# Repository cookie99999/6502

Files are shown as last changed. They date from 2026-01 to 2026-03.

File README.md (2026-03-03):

These are the relevant files for my ongoing WDC 65C816 based homebrew computer. It started off pretty similar to Ben Eater's 65C02 computer, but I've made significant changes since then and will continue to do so.

## Current Specs:
- WDC 65C816 clocked at 4MHz (reasonably stable at 6MHz, fails to boot at 8 likely due to slow memory/logic)
- 512K SRAM
- 8K NOR flash accessible to the user
- 2 6522 VIAs providing 2 8-bit GPIO ports and a couple timers and shift registers each
- 6551 ACIA UART for serial I/O. Rockwell part works only up to about 4MHz, but avoids the TX empty flag bug of the WDC part
- PS/2 interface provided by ATTiny26L on one of the VIA ports
- CompactFlash storage (via PATA adapter)
- VGA video output from a Pi Pico 2 providing text display and (very slow) bitmapped graphics
- expensive and oversized 4-layer PCB

## To do list:
- Bitbang an SPI RTC on a remaining VIA port
- possibly look into sound and/or joysticks on the other 2
- new PCB layout using more SMD/PLCC parts to reduce size and cost, with more SRAM and a proper DE-9 serial port

I've used and modified ideas from many sources, notably Ben Eater, Garth Wilson, Daryl Rictor, Grant Searle, and many users and articles on the 6502.org forum.

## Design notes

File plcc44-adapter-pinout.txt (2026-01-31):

dip  plcc
1    2
2    3 VCC
3    4
4    5
5    6
6    7 TDI
7    8
8    9
9    10 GND
10   11
11   13 TMS
12   14
13   15 VCC
14   NC
15   17
16   18
17   19
18   20
19   21
20   22 GND
21   24
22   25
23   26
24   27
25   28
26   29
27   30 GND
28   31
29   32 TCK
30   33
31   35 VCC
32   36
33   37
34   38 TDO
35   39
36   40
37   41
38   42 GND
39   43
40   44 OE1

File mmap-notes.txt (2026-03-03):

000000-00deff: ram
00df00-00df4f: io space, 16 bytes each for 5 devices
00df50-00dfff: unmapped
00e000-00ffff: rom
010000-ffffff: ram (currently 512k installed)

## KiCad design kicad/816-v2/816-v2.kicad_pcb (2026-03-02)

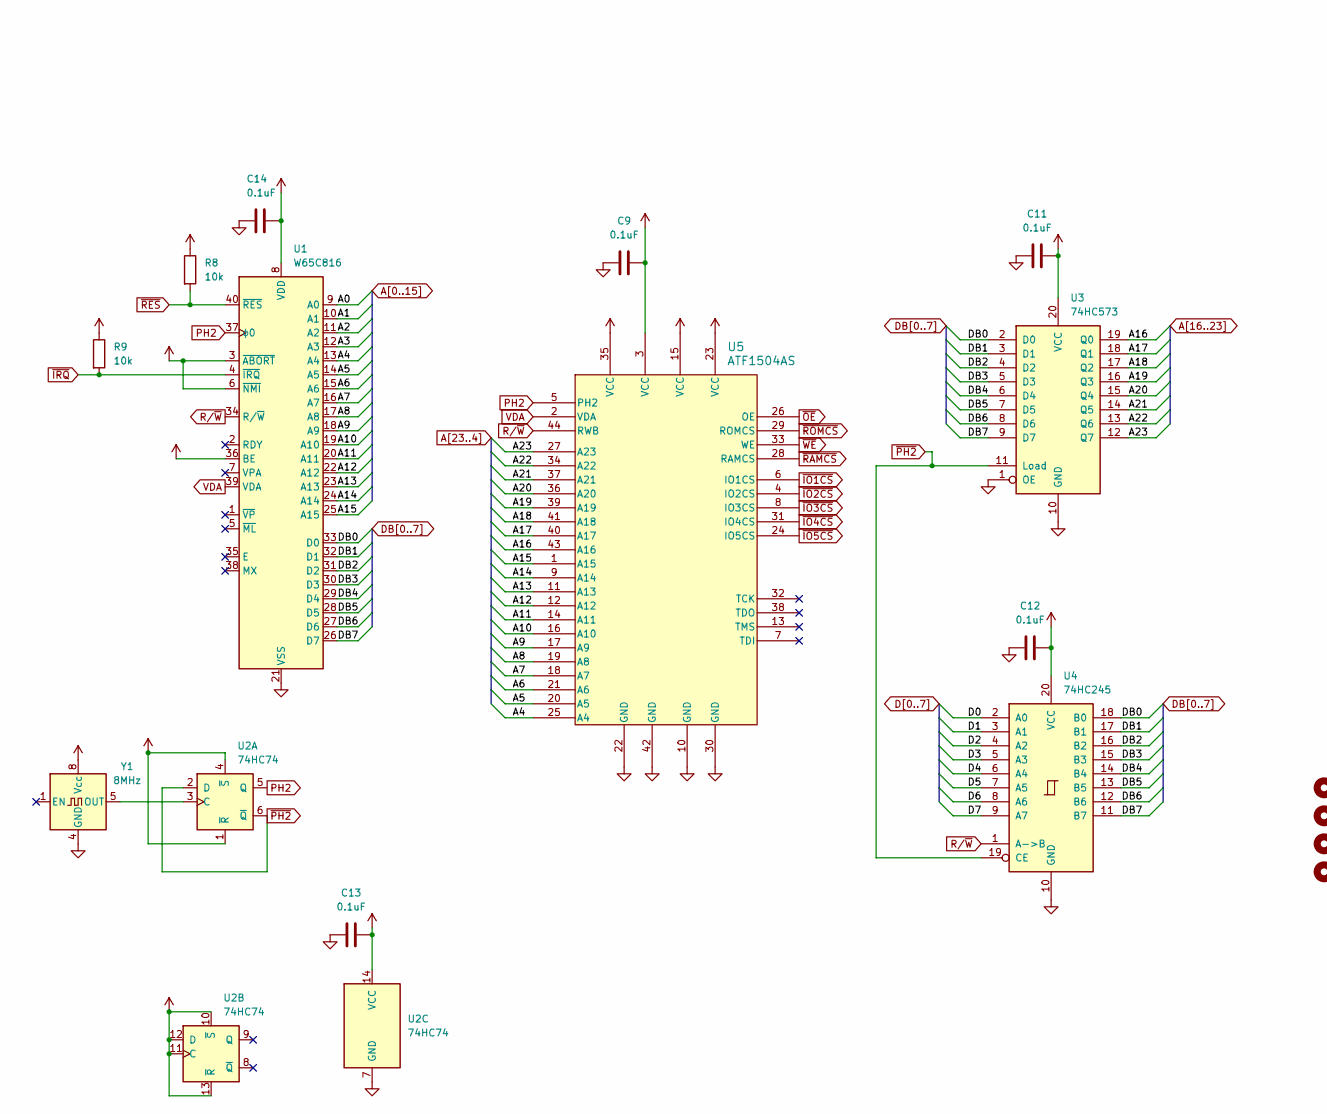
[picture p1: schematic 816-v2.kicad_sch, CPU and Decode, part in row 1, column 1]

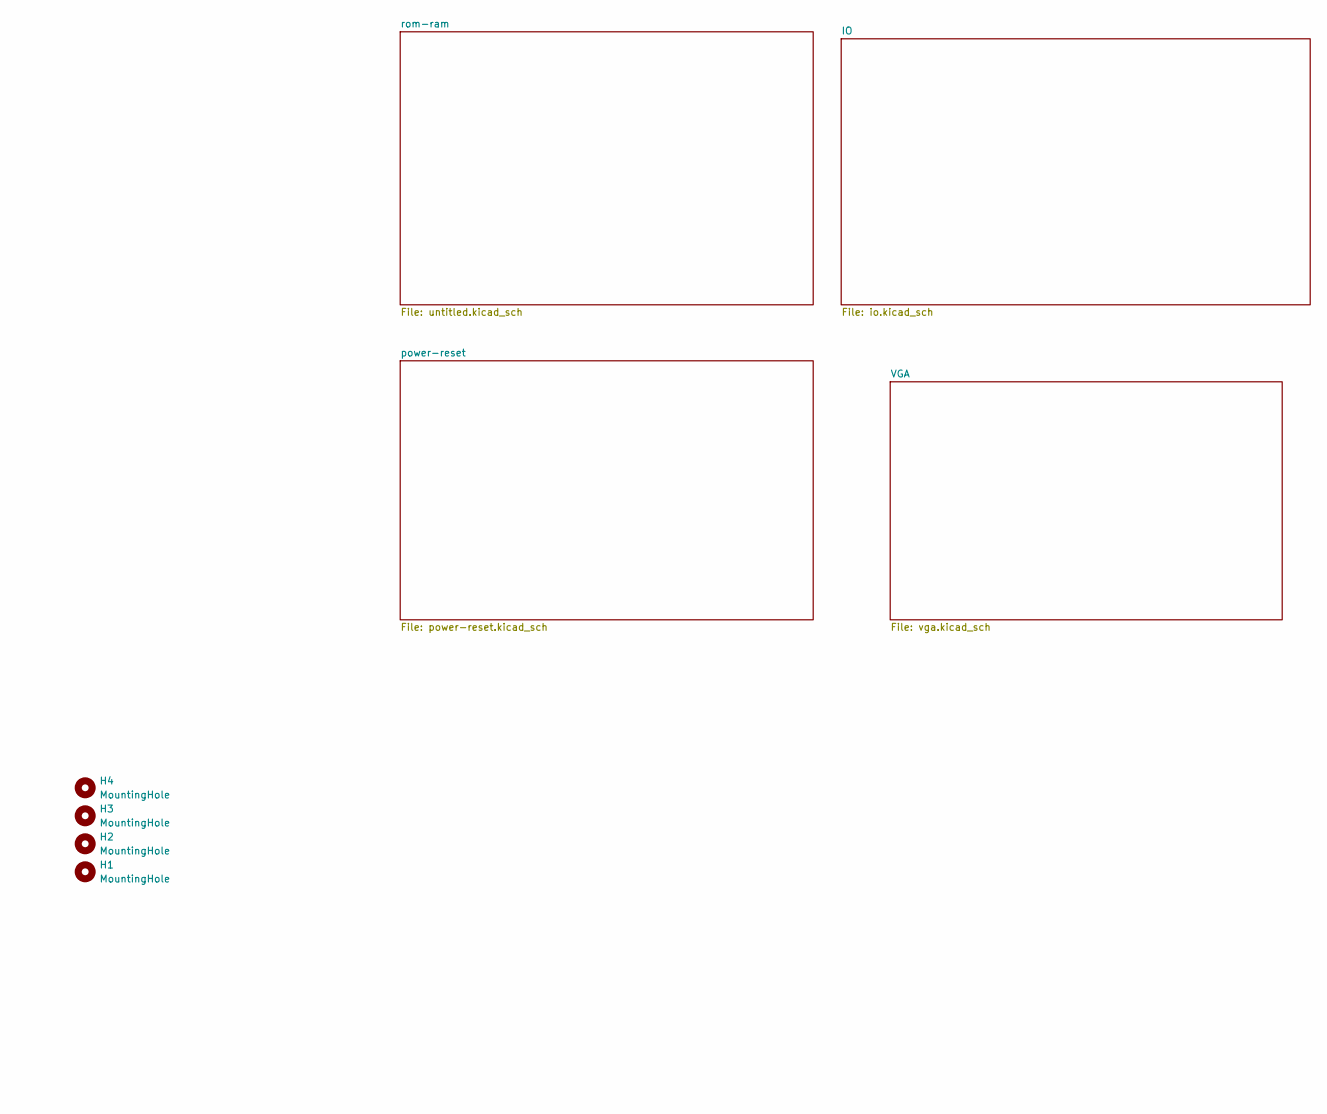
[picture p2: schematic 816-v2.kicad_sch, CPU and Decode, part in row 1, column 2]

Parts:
C9, C11, C12, C13, C14: 0.1uF; C_Disc_D4.3mm_W1.9mm_P5.00mm
H1, H2, H3, H4: MountingHole; MountingHole_3.2mm_M3
R8, R9: 10k; R_Axial_DIN0207_L6.3mm_D2.5mm_P7.62mm_Horizontal
U1: W65C816; DIP-40_W15.24mm_Socket
U2: 74HC74; DIP-14_W7.62mm_Socket
U3: 74HC573; DIP-20_W7.62mm_Socket
U4: 74HC245; DIP-20_W7.62mm_Socket
U5: ATF1504AS; PLCC-44_THT-Socket
Y1: 8MHz; DIP-8_W7.62mm_Socket

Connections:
A0: U1.9 (A0); also elsewhere on the board
A1: U1.10 (A1); also elsewhere on the board
A2: U1.11 (A2); also elsewhere on the board
A3: U1.12 (A3); also elsewhere on the board
A4: U1.13 (A4), U5.25 (A4); also elsewhere on the board
A5: U1.14 (A5), U5.20 (A5); also elsewhere on the board
A6: U1.15 (A6), U5.21 (A6); also elsewhere on the board
A7: U1.16 (A7), U5.18 (A7); also elsewhere on the board
A8: U1.17 (A8), U5.19 (A8); also elsewhere on the board
A9: U1.18 (A9), U5.17 (A9); also elsewhere on the board
A10: U1.19 (A10), U5.16 (A10); also elsewhere on the board
A11: U1.20 (A11), U5.14 (A11); also elsewhere on the board
A12: U1.22 (A12), U5.12 (A12); also elsewhere on the board
A13: U1.23 (A13), U5.11 (A13); also elsewhere on the board
A14: U1.24 (A14), U5.9 (A14); also elsewhere on the board
A15: U1.25 (A15), U5.1 (A15); also elsewhere on the board
A16: U3.19 (Q0), U5.43 (A16); also elsewhere on the board
A17: U3.18 (Q1), U5.40 (A17); also elsewhere on the board
A18: U3.17 (Q2), U5.41 (A18); also elsewhere on the board
A19: U3.16 (Q3), U5.39 (A19)
A20: U3.15 (Q4), U5.36 (A20)
A21: U3.14 (Q5), U5.37 (A21)
A22: U3.13 (Q6), U5.34 (A22)
A23: U3.12 (Q7), U5.27 (A23)
D0: U4.2 (A0); also elsewhere on the board
D1: U4.3 (A1); also elsewhere on the board
D2: U4.4 (A2); also elsewhere on the board
D3: U4.5 (A3); also elsewhere on the board
D4: U4.6 (A4); also elsewhere on the board
D5: U4.7 (A5); also elsewhere on the board
D6: U4.8 (A6); also elsewhere on the board
D7: U4.9 (A7); also elsewhere on the board
DB0: U1.33 (D0), U3.2 (D0), U4.18 (B0)
DB1: U1.32 (D1), U3.3 (D1), U4.17 (B1)
DB2: U1.31 (D2), U3.4 (D2), U4.16 (B2)
DB3: U1.30 (D3), U3.5 (D3), U4.15 (B3)
DB4: U1.29 (D4), U3.6 (D4), U4.14 (B4)
DB5: U1.28 (D5), U3.7 (D5), U4.13 (B5)
DB6: U1.27 (D6), U3.8 (D6), U4.12 (B6)
DB7: U1.26 (D7), U3.9 (D7), U4.11 (B7)
GND: C9.1, C11.2, C12.2, C13.2, C14.1, U1.21 (VSS), U2.7 (GND), U3.1 (OE), U3.10 (GND), U4.10 (GND), U5.10 (GND), U5.22 (GND), U5.30 (GND), U5.42 (GND), Y1.4 (GND); also elsewhere on the board
unnamed: U2.3 (C), Y1.5 (OUT)
PH2: U1.37 (ϕ0), U2.5 (Q), U5.5 (PH2); also elsewhere on the board
R/~W: U1.34 (R/~W), U4.1 (A->B), U5.44 (RWB); also elsewhere on the board
VCC: C9.2, C11.1, C12.1, C13.1, C14.2, R8.1, R9.1, U1.3 (~ABORT), U1.6 (~NMI), U1.8 (VDD), U1.36 (BE), U2.1 (~R), U2.4 (~S), U2.10 (~S), U2.11 (C), U2.12 (D), U2.13 (~R), U2.14 (VCC), U3.20 (VCC), U4.20 (VCC), U5.3 (VCC), U5.15 (VCC), U5.23 (VCC), U5.35 (VCC), Y1.8 (Vcc); also elsewhere on the board
VDA: U1.39 (VDA), U5.2 (VDA)
~IO1CS: U5.6 (IO1CS); also elsewhere on the board
~IO2CS: U5.4 (IO2CS); also elsewhere on the board
~IO3CS: U5.8 (IO3CS); also elsewhere on the board
~IO4CS: U5.31 (IO4CS); also elsewhere on the board
~IO5CS: U5.24 (IO5CS); also elsewhere on the board
~IRQ: R9.2, U1.4 (~IRQ); also elsewhere on the board
~OE: U5.26 (OE); also elsewhere on the board
~PH2: U2.2 (D), U2.6 (~Q), U3.11 (Load), U4.19 (CE)
~RAMCS: U5.28 (RAMCS); also elsewhere on the board
~RES: R8.2, U1.40 (~RES); also elsewhere on the board
~ROMCS: U5.29 (ROMCS); also elsewhere on the board
~WE: U5.33 (WE); also elsewhere on the board

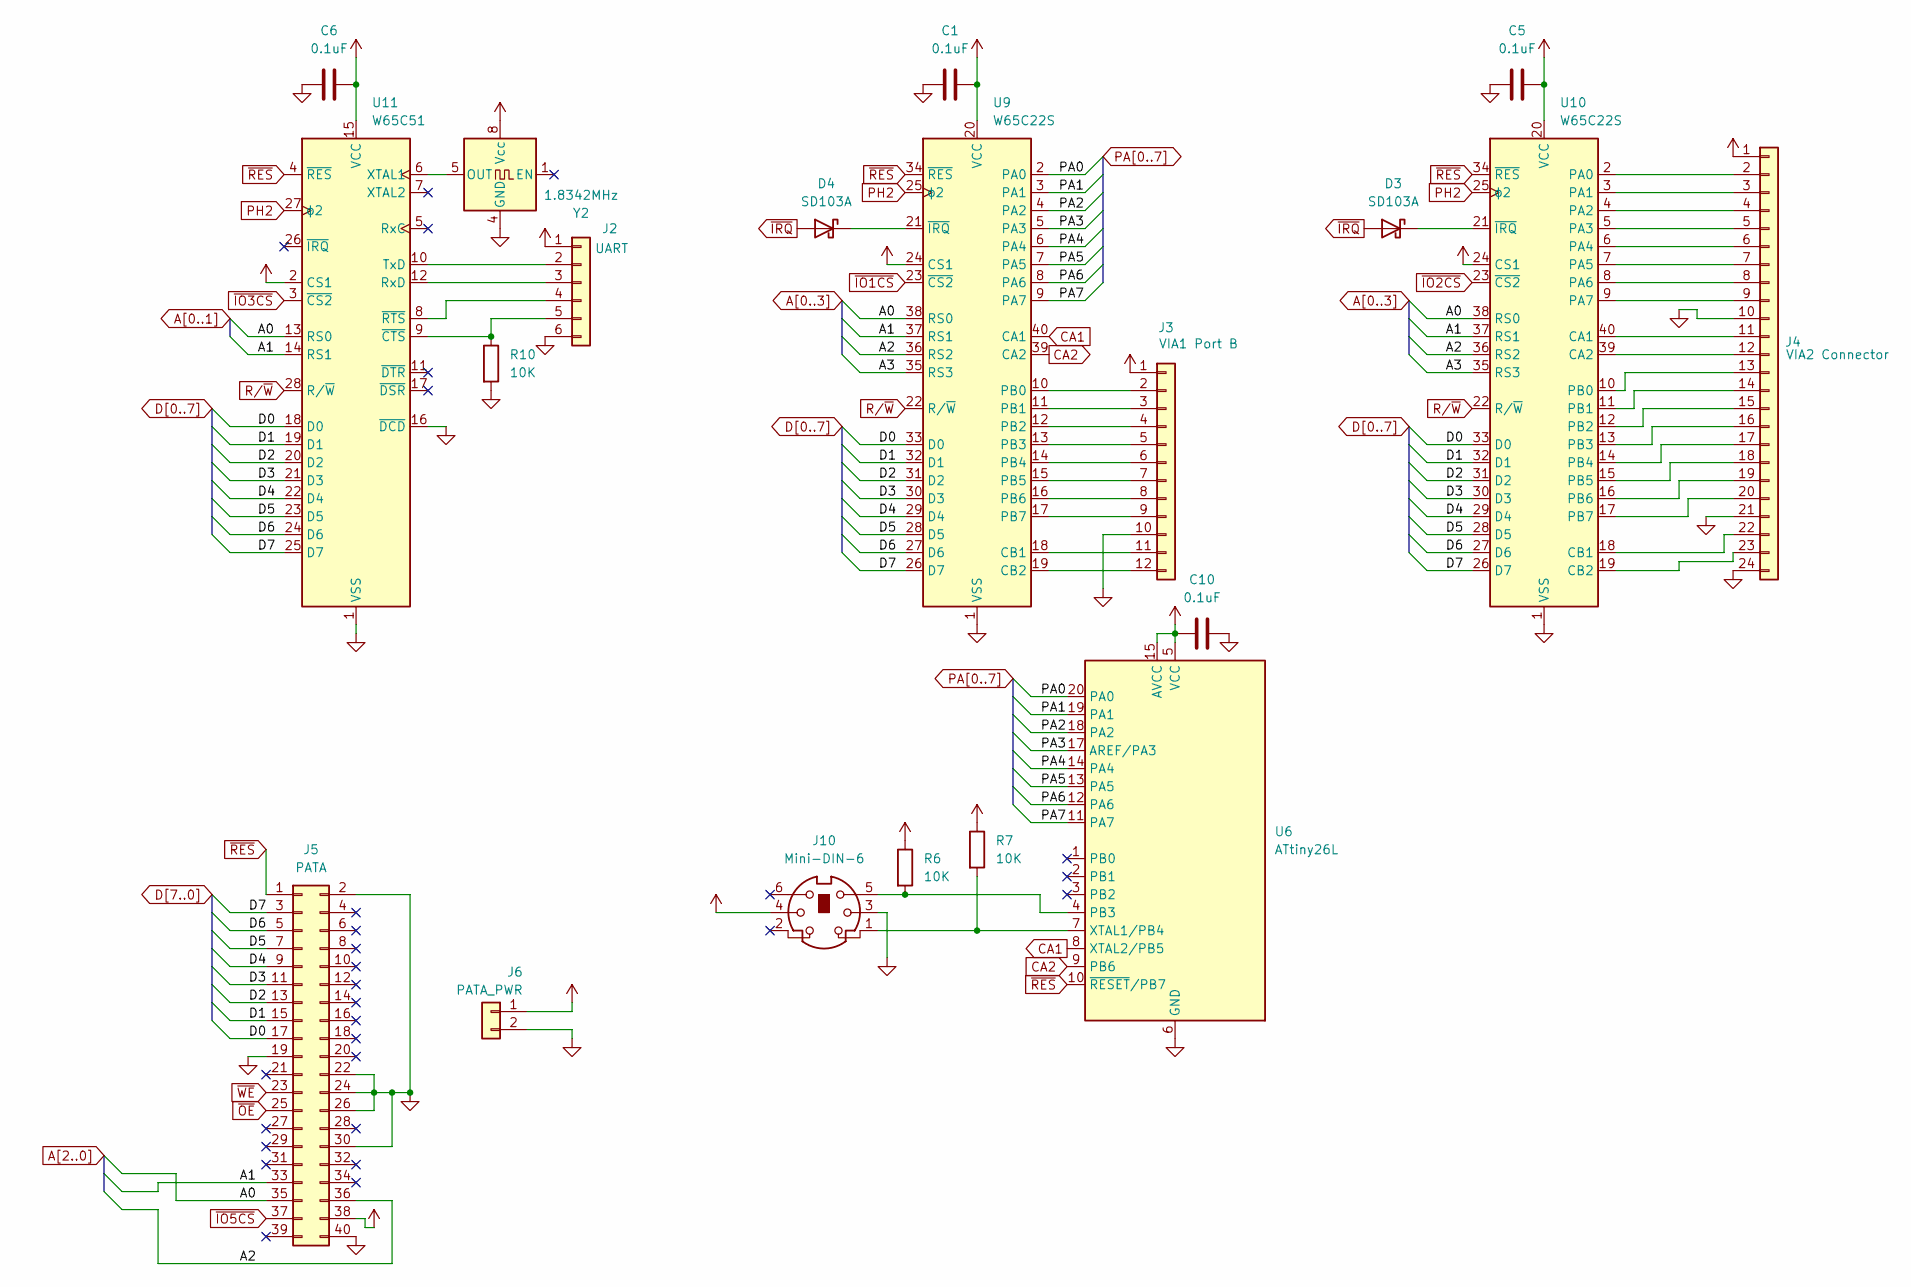
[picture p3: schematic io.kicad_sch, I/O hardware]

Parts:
C1, C5, C6, C10: 0.1uF; C_Disc_D4.3mm_W1.9mm_P5.00mm
D3, D4: SD103A; D_DO-35_SOD27_P7.62mm_Horizontal
J2: UART; PinHeader_1x06_P2.54mm_Vertical
J3: VIA1 Port B; PinHeader_2x06_P2.54mm_Vertical
J4: VIA2 Connector; PinHeader_2x12_P2.54mm_Vertical
J5: PATA; IDC-Header_2x20_P2.54mm_Vertical
J6: PATA_PWR; PinHeader_1x02_P2.54mm_Vertical
J10: Mini-DIN-6; TE_5749180-1
R6, R7, R10: 10K; R_Axial_DIN0207_L6.3mm_D2.5mm_P7.62mm_Horizontal
U6: ATtiny26L; DIP-20_W7.62mm_Socket
U9, U10: W65C22S; DIP-40_W15.24mm_Socket
U11: W65C51; DIP-28_W15.24mm_Socket
Y2: 1.8342MHz; Oscillator_DIP-8

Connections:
A0: J5.35, U9.38 (RS0), U10.38 (RS0), U11.13 (RS0); also elsewhere on the board
A1: J5.33, U9.37 (RS1), U10.37 (RS1), U11.14 (RS1); also elsewhere on the board
A2: J5.36, U9.36 (RS2), U10.36 (RS2); also elsewhere on the board
A3: U9.35 (RS3), U10.35 (RS3); also elsewhere on the board
CA1: U6.8 (XTAL2/PB5), U9.40 (CA1)
CA2: U6.9 (PB6), U9.39 (CA2)
D0: J5.17, U9.33 (D0), U10.33 (D0), U11.18 (D0); also elsewhere on the board
D1: J5.15, U9.32 (D1), U10.32 (D1), U11.19 (D1); also elsewhere on the board
D2: J5.13, U9.31 (D2), U10.31 (D2), U11.20 (D2); also elsewhere on the board
D3: J5.11, U9.30 (D3), U10.30 (D3), U11.21 (D3); also elsewhere on the board
D4: J5.9, U9.29 (D4), U10.29 (D4), U11.22 (D4); also elsewhere on the board
D5: J5.7, U9.28 (D5), U10.28 (D5), U11.23 (D5); also elsewhere on the board
D6: J5.5, U9.27 (D6), U10.27 (D6), U11.24 (D6); also elsewhere on the board
D7: J5.3, U9.26 (D7), U10.26 (D7), U11.25 (D7); also elsewhere on the board
GND: C1.2, C5.2, C6.2, C10.2, J2.6, J3.10, J4.10, J4.21, J4.24, J5.2, J5.19, J5.22, J5.24, J5.26, J5.30, J5.40, J6.2, J10.3, R10.2, U6.6 (GND), U6.16 (GND), U9.1 (VSS), U10.1 (VSS), U11.1 (VSS), U11.16 (~DCD), Y2.4 (GND); also elsewhere on the board
unnamed: D3.1 (K), U10.21 (~IRQ)
unnamed: D4.1 (K), U9.21 (~IRQ)
unnamed: J2.2, U11.10 (TxD)
unnamed: J2.3, U11.12 (RxD)
unnamed: J2.4, U11.8 (~RTS)
unnamed: J2.5, R10.1, U11.9 (~CTS)
unnamed: J3.2, U9.10 (PB0)
unnamed: J3.3, U9.11 (PB1)
unnamed: J3.4, U9.12 (PB2)
unnamed: J3.5, U9.13 (PB3)
unnamed: J3.6, U9.14 (PB4)
unnamed: J3.7, U9.15 (PB5)
unnamed: J3.8, U9.16 (PB6)
unnamed: J3.9, U9.17 (PB7)
unnamed: J3.11, U9.18 (CB1)
unnamed: J3.12, U9.19 (CB2)
unnamed: J4.2, U10.2 (PA0)
unnamed: J4.3, U10.3 (PA1)
unnamed: J4.4, U10.4 (PA2)
unnamed: J4.5, U10.5 (PA3)
unnamed: J4.6, U10.6 (PA4)
unnamed: J4.7, U10.7 (PA5)
unnamed: J4.8, U10.8 (PA6)
unnamed: J4.9, U10.9 (PA7)
unnamed: J4.11, U10.40 (CA1)
unnamed: J4.12, U10.39 (CA2)
unnamed: J4.13, U10.10 (PB0)
unnamed: J4.14, U10.11 (PB1)
unnamed: J4.15, U10.12 (PB2)
unnamed: J4.16, U10.13 (PB3)
unnamed: J4.17, U10.14 (PB4)
unnamed: J4.18, U10.15 (PB5)
unnamed: J4.19, U10.16 (PB6)
unnamed: J4.20, U10.17 (PB7)
unnamed: J4.22, U10.18 (CB1)
unnamed: J4.23, U10.19 (CB2)
unnamed: J10.5, R6.2, U6.4 (PB3)
unnamed: J10.1, R7.2, U6.7 (XTAL1/PB4)
unnamed: U11.6 (XTAL1), Y2.5 (OUT)
PA0: U6.20 (PA0), U9.2 (PA0)
PA1: U6.19 (PA1), U9.3 (PA1)
PA2: U6.18 (PA2), U9.4 (PA2)
PA3: U6.17 (AREF/PA3), U9.5 (PA3)
PA4: U6.14 (PA4), U9.6 (PA4)
PA5: U6.13 (PA5), U9.7 (PA5)
PA6: U6.12 (PA6), U9.8 (PA6)
PA7: U6.11 (PA7), U9.9 (PA7)
PH2: U9.25 (ϕ2), U10.25 (ϕ2), U11.27 (ϕ2); also elsewhere on the board
R/~W: U9.22 (R/~W), U10.22 (R/~W), U11.28 (R/~W); also elsewhere on the board
VCC: C1.1, C5.1, C6.1, C10.1, J2.1, J3.1, J4.1, J5.38, J6.1, J10.4, R6.1, R7.1, U6.5 (VCC), U6.15 (AVCC), U9.20 (VCC), U9.24 (CS1), U10.20 (VCC), U10.24 (CS1), U11.2 (CS1), U11.15 (VCC), Y2.8 (Vcc); also elsewhere on the board
~IO1CS: U9.23 (~CS2); also elsewhere on the board
~IO2CS: U10.23 (~CS2); also elsewhere on the board
~IO3CS: U11.3 (~CS2); also elsewhere on the board
~IO5CS: J5.37; also elsewhere on the board
~IRQ: D3.2 (A), D4.2 (A); also elsewhere on the board
~OE: J5.25; also elsewhere on the board
~RES: J5.1, U6.10 (~RESET/PB7), U9.34 (~RES), U10.34 (~RES), U11.4 (~RES); also elsewhere on the board
~WE: J5.23; also elsewhere on the board

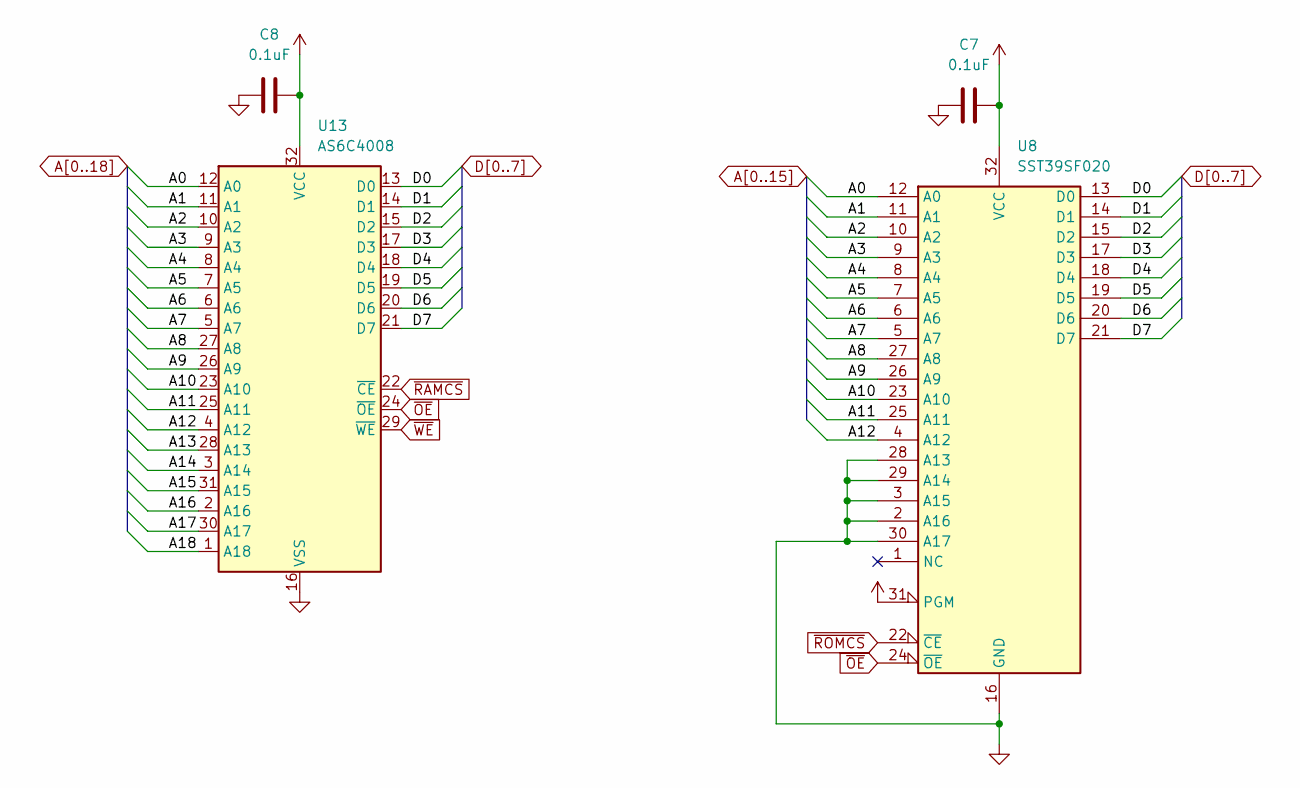
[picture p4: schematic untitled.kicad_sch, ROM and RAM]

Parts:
C7, C8: 0.1uF; C_Disc_D4.3mm_W1.9mm_P5.00mm
U8: SST39SF020; DIP-32_W15.24mm_Socket
U13: AS6C4008; DIP-32_W15.24mm_Socket

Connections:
A0: U8.12 (A0), U13.12 (A0); also elsewhere on the board
A1: U8.11 (A1), U13.11 (A1); also elsewhere on the board
A2: U8.10 (A2), U13.10 (A2); also elsewhere on the board
A3: U8.9 (A3), U13.9 (A3); also elsewhere on the board
A4: U8.8 (A4), U13.8 (A4); also elsewhere on the board
A5: U8.7 (A5), U13.7 (A5); also elsewhere on the board
A6: U8.6 (A6), U13.6 (A6); also elsewhere on the board
A7: U8.5 (A7), U13.5 (A7); also elsewhere on the board
A8: U8.27 (A8), U13.27 (A8); also elsewhere on the board
A9: U8.26 (A9), U13.26 (A9); also elsewhere on the board
A10: U8.23 (A10), U13.23 (A10); also elsewhere on the board
A11: U8.25 (A11), U13.25 (A11); also elsewhere on the board
A12: U8.4 (A12), U13.4 (A12); also elsewhere on the board
A13: U13.28 (A13); also elsewhere on the board
A14: U13.3 (A14); also elsewhere on the board
A15: U13.31 (A15); also elsewhere on the board
A16: U13.2 (A16); also elsewhere on the board
A17: U13.30 (A17); also elsewhere on the board
A18: U13.1 (A18); also elsewhere on the board
D0: U8.13 (D0), U13.13 (D0); also elsewhere on the board
D1: U8.14 (D1), U13.14 (D1); also elsewhere on the board
D2: U8.15 (D2), U13.15 (D2); also elsewhere on the board
D3: U8.17 (D3), U13.17 (D3); also elsewhere on the board
D4: U8.18 (D4), U13.18 (D4); also elsewhere on the board
D5: U8.19 (D5), U13.19 (D5); also elsewhere on the board
D6: U8.20 (D6), U13.20 (D6); also elsewhere on the board
D7: U8.21 (D7), U13.21 (D7); also elsewhere on the board
GND: C7.2, C8.2, U8.2 (A16), U8.3 (A15), U8.16 (GND), U8.28 (A13), U8.29 (A14), U8.30 (A17), U13.16 (VSS); also elsewhere on the board
VCC: C7.1, C8.1, U8.31 (PGM), U8.32 (VCC), U13.32 (VCC); also elsewhere on the board
~OE: U8.24 (~OE), U13.24 (~OE); also elsewhere on the board
~RAMCS: U13.22 (~CE); also elsewhere on the board
~ROMCS: U8.22 (~CE); also elsewhere on the board
~WE: U13.29 (~WE); also elsewhere on the board

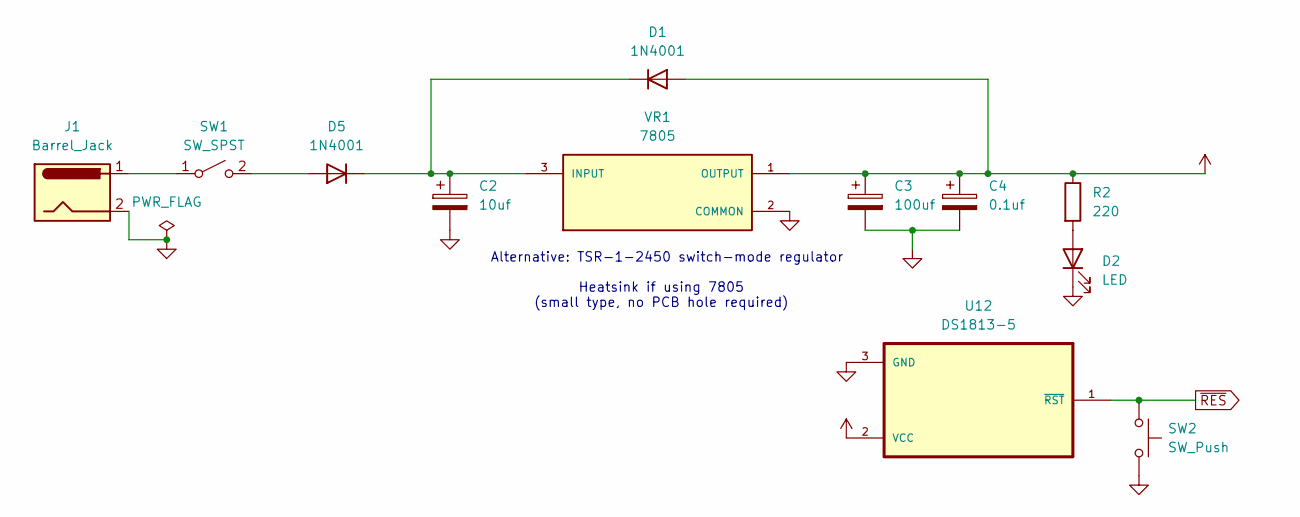
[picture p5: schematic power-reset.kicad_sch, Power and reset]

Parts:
C2: 10uf; CP_Radial_D5.0mm_P2.50mm
C3: 100uf; CP_Radial_D5.0mm_P2.50mm
C4: 0.1uf; C_Disc_D4.3mm_W1.9mm_P5.00mm
D1, D5: 1N4001; D_DO-41_SOD81_P10.16mm_Horizontal
D2: LED; LED_D5.0mm
J1: Barrel_Jack; BarrelJack_Horizontal
R2: 220; R_Axial_DIN0207_L6.3mm_D2.5mm_P7.62mm_Horizontal
SW1: SW_SPST; SW_Slide_SPDT_Straight_CK_OS102011MS2Q
SW2: SW_Push; SW_PUSH_6mm
U12: DS1813-5; TO-92L
VR1: 7805; TO-220-3_Vertical; PARTREV V

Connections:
GND: C2.2, C3.2, C4.2, D2.1 (K), J1.2, SW2.2, U12.3 (GND), VR1.2 (COMMON); also elsewhere on the board
unnamed: C2.1, D1.1 (K), D5.1 (K), VR1.3 (INPUT)
unnamed: D2.2 (A), R2.2
unnamed: D5.2 (A), SW1.2 (B)
unnamed: J1.1, SW1.1 (A)
VCC: C3.1, C4.1, D1.2 (A), R2.1, U12.2 (VCC), VR1.1 (OUTPUT); also elsewhere on the board
~RES: SW2.1, U12.1 (~RST); also elsewhere on the board

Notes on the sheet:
Heatsink if using 7805 (small type, no PCB hole required)
Alternative: TSR-1-2450 switch-mode regulator

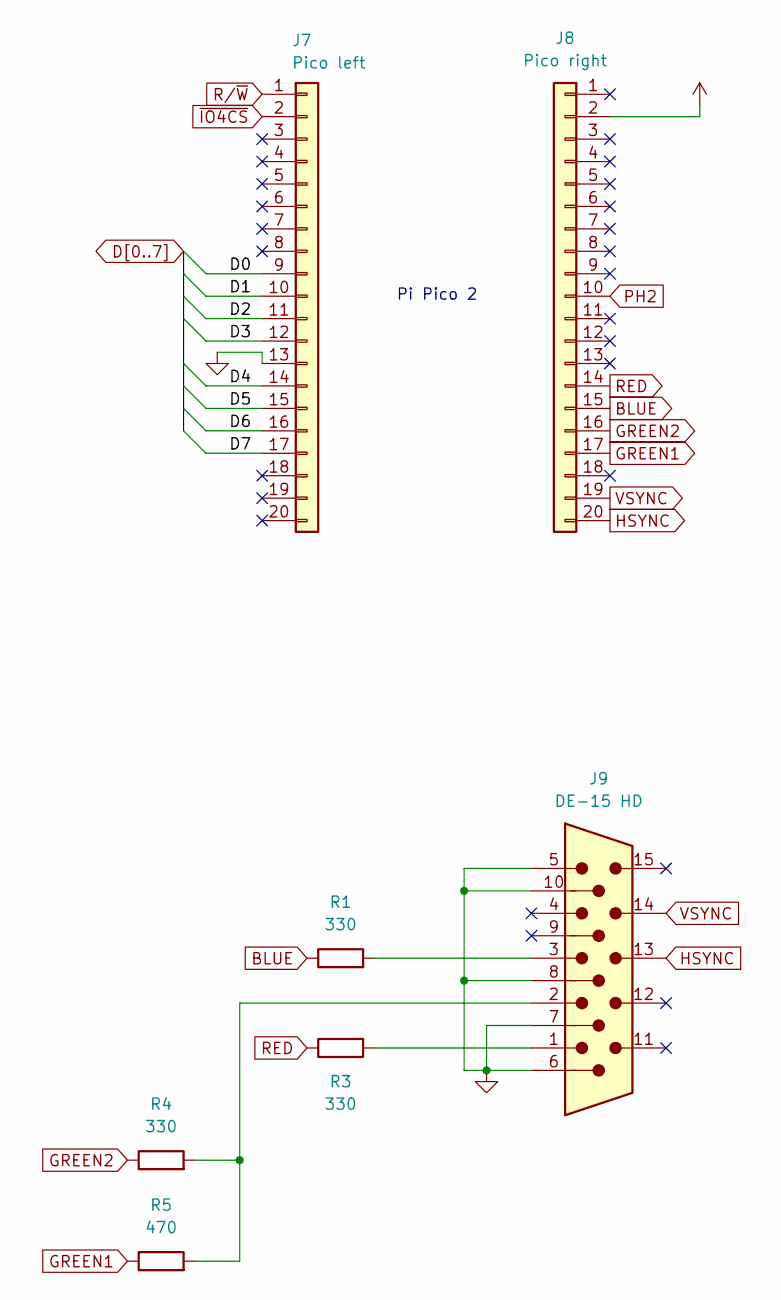
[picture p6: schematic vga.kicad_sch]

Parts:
J7: Pico left; PinHeader_1x20_P2.54mm_Vertical
J8: Pico right; PinHeader_1x20_P2.54mm_Vertical
J9: DE-15 HD; AMPHENOL_ICD15S13E4GV00LF
R1, R3, R4: 330; R_Axial_DIN0207_L6.3mm_D2.5mm_P7.62mm_Horizontal
R5: 470; R_Axial_DIN0207_L6.3mm_D2.5mm_P7.62mm_Horizontal

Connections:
BLUE: J8.15, R1.1
D0: J7.9; also elsewhere on the board
D1: J7.10; also elsewhere on the board
D2: J7.11; also elsewhere on the board
D3: J7.12; also elsewhere on the board
D4: J7.14; also elsewhere on the board
D5: J7.15; also elsewhere on the board
D6: J7.16; also elsewhere on the board
D7: J7.17; also elsewhere on the board
GND: J7.13, J9.5, J9.6, J9.7, J9.8, J9.10; also elsewhere on the board
GREEN1: J8.17, R5.1
GREEN2: J8.16, R4.1
HSYNC: J8.20, J9.13
unnamed: J9.1, R3.2
unnamed: J9.2, R4.2, R5.2
unnamed: J9.3, R1.2
PH2: J8.10; also elsewhere on the board
RED: J8.14, R3.1
R/~W: J7.1; also elsewhere on the board
VCC: J8.2; also elsewhere on the board
VSYNC: J8.19, J9.14
~IO4CS: J7.2; also elsewhere on the board

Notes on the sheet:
Pi Pico 2

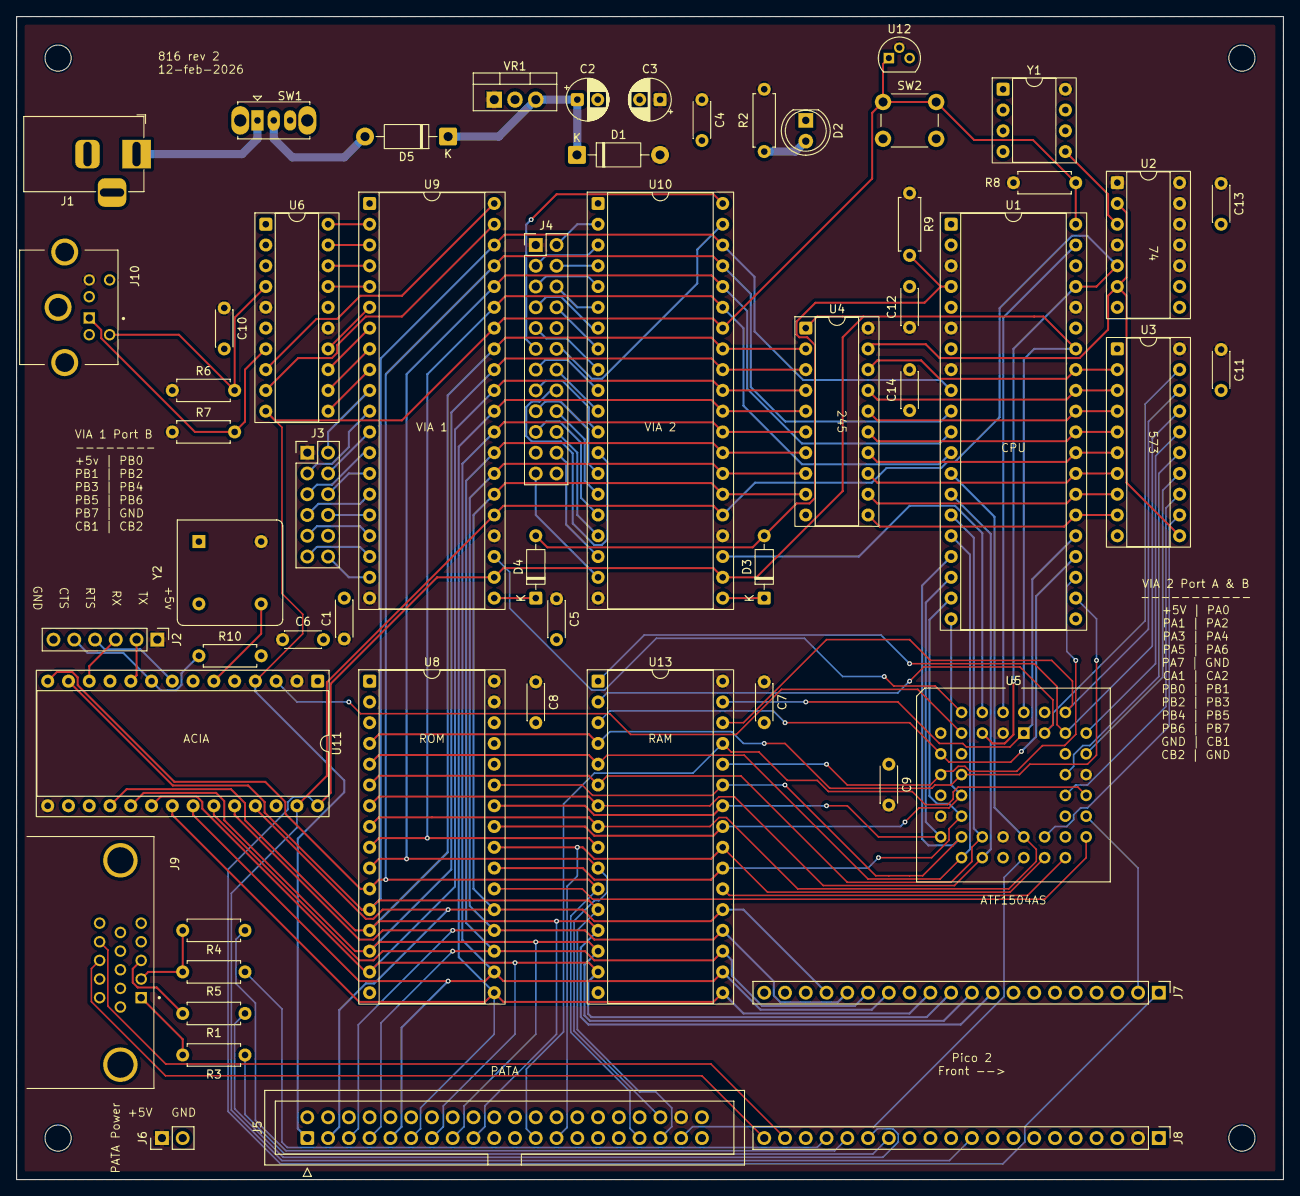
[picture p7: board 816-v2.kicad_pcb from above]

Board: 4 copper layers, 154.9 x 142.2 mm, 60 parts (0 on the bottom side), 120 nets.

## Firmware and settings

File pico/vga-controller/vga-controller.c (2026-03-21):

#include <stdio.h>
#include <stdint.h>
#include <math.h>
#include "pico/stdlib.h"
#include "hardware/gpio.h"
#include "hardware/pio.h"
#include "hardware/clocks.h"
#include "hardware/structs/bus_ctrl.h"

#include "dbus.pio.h"
#include "vga_graphics.h"

#define D0 6
#define D1 7
#define D2 8
#define D3 9
#define D4 10
#define D5 11
#define D6 12
#define D7 13

#define RWB 0
#define CSB 1
#define PH2 26
#define RESB 22

static uint8_t dbus_buf[5120];
static uint8_t *dbus_bufend = dbus_buf + sizeof(dbus_buf);
volatile static uint8_t *dbus_rptr = dbus_buf;
volatile static uint8_t *dbus_wptr = dbus_buf;
static PIO dbus_pio;
static uint dbus_sm;
static uint dbus_offset;
static uint dbus_pio_irq;

volatile static bool cursor_state = false;
extern unsigned char *framebuf;
#define FBUF_SIZE 153600 * 2;
volatile uint32_t fbuf_addr = 0;
volatile bool lores = false;
volatile struct repeating_timer timer;
extern char textcolor;
extern char textbgcolor;
extern unsigned short textsize;
extern unsigned short cursor_x;
extern unsigned short cursor_y;
#define WIDTH 640
#define HEIGHT 480

enum states {
  TEXT_MODE,
  BITMAP_MODE,
  TILEMAP_MODE
};
volatile static char cur_state = TEXT_MODE;

enum cmds {
  DRAW_PIXEL = 0, GO_TEXT, GO_TILE, GO_BITMAP, CLEAR, DRAW_TRI, RES0,
  RES1, BACKSPACE, RES2, LF, RES3, RES4, CR, GO_LORES, GO_HIRES,
  SET_ADDR = 0x7e, WRITE_RAW, DRAW_PIX_SEQ = 0x80,
  RESET = 0xff
};

static void __not_in_flash_func(read_dbus)(void) {
  *dbus_wptr++ = dbus_pio->rxf[dbus_sm] >> 24;
  dbus_pio->irq = (1u << 0);
  if (dbus_wptr >= dbus_bufend)
    dbus_wptr = dbus_buf;
}

__attribute__((optimize("O0"))) bool get_dbus_byte(uint8_t *byte) {
  if (dbus_rptr != dbus_wptr) {
    *byte = *dbus_rptr++;
    if (dbus_rptr >= dbus_bufend)
      dbus_rptr = dbus_buf;
    return true;
  }
  return false;
}

__attribute__((optimize("O0"))) uint8_t get_dbus_byte_blocking() {
  while (dbus_rptr == dbus_wptr) {
    ;
  }
  uint8_t byte;
  byte = *dbus_rptr++;
  if (dbus_rptr >= dbus_bufend)
    dbus_rptr = dbus_buf;
  return byte;
}

bool toggle_cursor(__unused struct repeating_timer *t) {
  if (cursor_state) {
    fill_rect(cursor_x, cursor_y, 6, 8, textcolor);
  } else {
    fill_rect(cursor_x, cursor_y, 6, 8, textbgcolor);
  }
  cursor_state = !cursor_state;
  return true;
}

void vga_reset() {
  cur_state = TEXT_MODE;
  lores = false;
  fbuf_addr = 0;
  cancel_repeating_timer(&timer);
  fill_rect(0, 0, 640, 480, CYAN);
  set_text_size(1);
  set_text_wrap(1);
  set_cursor(0, 0);
  set_text_color(BLACK, CYAN);
  add_repeating_timer_ms(500, toggle_cursor, NULL, &timer);
}

void text_task(uint8_t byte);
void bitmap_task(uint8_t byte);

void dbus_task(void) {
  uint8_t byte;
  if (get_dbus_byte(&byte)) {
    if (byte == RESET) {
      vga_reset();
      return;
    }
    switch (cur_state) {
    case TEXT_MODE:
      text_task(byte);
      break;
    case BITMAP_MODE:
      bitmap_task(byte);
      break;
    default:
      break;
    }
  }
}

void text_task(uint8_t byte) {
  switch (byte) {
  case GO_BITMAP:
    cancel_repeating_timer(&timer);
    fill_rect(cursor_x, cursor_y, 6, 8, textbgcolor);
    cur_state = BITMAP_MODE;
    break;
  case CLEAR:
    fill_rect(0, 0, 640, 480, textbgcolor);
    cursor_x = 0;
    cursor_y = 0;
    break;
  case BACKSPACE:
    fill_rect(cursor_x, cursor_y, 6, 8, textbgcolor);
    cursor_x -= textsize * 6;
    if (cursor_x < 0) {
      cursor_y -= textsize * 8;
      cursor_x = (WIDTH - (textsize * 6));
    }
    fill_rect(cursor_x, cursor_y, 6 * textsize, 8 * textsize, textbgcolor);
    break;
  default:
    cancel_repeating_timer(&timer);
    fill_rect(cursor_x, cursor_y, 6, 8, textbgcolor);
    draw_char_cursor(byte);
    add_repeating_timer_ms(500, toggle_cursor, NULL, &timer);
    break;
  }
}

void bitmap_task(uint8_t byte) {
  switch (byte) {
  case DRAW_PIXEL: //draw pixel xlo xhi ylo yhi color
    {
      uint16_t x = (uint16_t)get_dbus_byte_blocking();
      x = x | ((uint16_t)get_dbus_byte_blocking() << 8);
      uint16_t y = (uint16_t)get_dbus_byte_blocking();
      y = y | ((uint16_t)get_dbus_byte_blocking() << 8);
      uint8_t color = get_dbus_byte_blocking();
      draw_pixel(x, y, color);
    }
    break;
  case GO_LORES:
    lores = true;
    break;
  case GO_HIRES:
    lores = false;
    break;
  case DRAW_PIX_SEQ: //pixel data in low nibble of command
  case DRAW_PIX_SEQ+1:
  case DRAW_PIX_SEQ+2:
  case DRAW_PIX_SEQ+3:
  case DRAW_PIX_SEQ+4:
  case DRAW_PIX_SEQ+5:
  case DRAW_PIX_SEQ+6:
  case DRAW_PIX_SEQ+7:
  case DRAW_PIX_SEQ+8:
  case DRAW_PIX_SEQ+9:
  case DRAW_PIX_SEQ+10:
  case DRAW_PIX_SEQ+11:
  case DRAW_PIX_SEQ+12:
  case DRAW_PIX_SEQ+13:
  case DRAW_PIX_SEQ+14:
  case DRAW_PIX_SEQ+15:
    {
      uint8_t color = byte & 0x0f;
      if (!lores) {
	uint16_t y = (fbuf_addr / WIDTH) + 1;
	uint16_t x = (fbuf_addr % WIDTH) + 1;
	draw_pixel(x, y, color);
	fbuf_addr++;
	if (fbuf_addr >= (WIDTH * HEIGHT))
	  fbuf_addr = 0;
      } else {
	uint16_t y = (fbuf_addr / 128) * 5;
	uint16_t x = (fbuf_addr % 128) * 5;
	fill_rect(x, y, 5, 5, color);
	fbuf_addr++;
	if (fbuf_addr >= (128 * 96))
	  fbuf_addr = 0;
      }
    }
    break;
  case WRITE_RAW: //byte
    {
      uint8_t byte = get_dbus_byte_blocking();
      framebuf[fbuf_addr] = byte;
    }
    break;
  case DRAW_TRI: //draw_tri x1[2] y1[2] x2[2] y2[2] x3[2] y3[2] color
    {
      uint16_t x1 = (uint16_t)get_dbus_byte_blocking();
      x1 = x1 | ((uint16_t)get_dbus_byte_blocking() << 8);
      uint16_t y1 = (uint16_t)get_dbus_byte_blocking();
      y1 = y1 | ((uint16_t)get_dbus_byte_blocking() << 8);
      
      uint16_t x2 = (uint16_t)get_dbus_byte_blocking();
      x2 = x2 | ((uint16_t)get_dbus_byte_blocking() << 8);
      uint16_t y2 = (uint16_t)get_dbus_byte_blocking();
      y2 = y2 | ((uint16_t)get_dbus_byte_blocking() << 8);
      
      uint16_t x3 = (uint16_t)get_dbus_byte_blocking();
      x3 = x3 | ((uint16_t)get_dbus_byte_blocking() << 8);
      uint16_t y3 = (uint16_t)get_dbus_byte_blocking();
      y3 = y3 | ((uint16_t)get_dbus_byte_blocking() << 8);
      uint8_t color = get_dbus_byte_blocking();
      
      draw_tri(x1, y1, x2, y2, x3, y3, color);
    }
    break;
  case CLEAR: //clear color
    {
      uint8_t color = get_dbus_byte_blocking();
      fill_rect(0, 0, 640, 480, color);
    }
    break;
  case GO_TEXT:
    add_repeating_timer_ms(500, toggle_cursor, NULL, &timer);
    cur_state = TEXT_MODE;
    break;
  default:
    break;
  }
}

void tile_task(uint8_t byte) {

}

typedef struct {
  float x;
  float y;
  float z;
} vec3;

typedef struct {
  unsigned short rows;
  unsigned short cols;
  float m[4][4];
} matrix;

matrix newmat(unsigned short r, unsigned short c) {
  matrix m = { r, c, {
	   {0, 0, 0, 0},
	   {0, 0, 0, 0},
	   {0, 0, 0, 0},
	   {0, 0, 0, 0}}};
  return m;
}

matrix v2m(vec3 v) {
  matrix result = newmat(4, 1);
  result.m[0][0] = v.x;
  result.m[1][0] = v.y;
  result.m[2][0] = v.z;
  result.m[3][0] = 1.;
  return result;
}

vec3 m2v(matrix m) {
  vec3 result = { m.m[0][0] / m.m[3][0],
		  m.m[1][0] / m.m[3][0],
		  m.m[2][0] / m.m[3][0]};
  return result;
}

matrix matmul(matrix a, matrix b) {
  matrix result = newmat(a.rows, b.cols);
  for (int i = 0; i < a.rows; i++) {
    for (int j = 0; j < b.cols; j++) {
      result.m[i][j] = 0.;
      for (int k = 0; k < a.cols; k++) {
	result.m[i][j] += a.m[i][k] * b.m[k][j];
      }
    }
  }
  return result;
}

typedef struct {
  vec3 v1;
  vec3 v2;
  vec3 v3;
} tri;

void identity(matrix *m) {
  for (int i = 0; i < m->cols; i++) {
    for (int j = 0; j < m->rows; j++) {
      m->m[i][j] = i == j ? 1. : 0.;
    }
  }
}

vec3 project(vec3 v) {
  vec3 result = { (v.x + 1.) * WIDTH/2., (v.y + 1.) * HEIGHT/2., (v.z + 1.) * 255./2. };
  return result;
}

vec3 persp(vec3 v) {
  float c = 1. - v.z / 3.;
  vec3 result;
  result.x = v.x / c;
  result.y = v.y / c;
  result.z = v.z / c;
  return result;
}

vec3 rot(vec3 v) {
  float a = M_PI/6.;
  float cosy = cosf(a);
  float siny = sinf(a);
  matrix roty = newmat(3, 3);
  roty.m[0][0] = cosy;
  roty.m[0][1] = 0.;
  roty.m[0][2] = siny;

  roty.m[1][0] = 0.;
  roty.m[1][1] = 1.;
  roty.m[1][2] = 0.;

  roty.m[2][0] = -siny;
  roty.m[2][1] = 0.;
  roty.m[2][2] = cosy;
  return m2v(matmul(roty, v2m(v)));
}

void threed_demo() {
  tri cube_faces[12] = {
    { {0, 0, -0.8}, {0, 0, 0}, {0, -0.8, 0} },
    { {0, 0, -0.8}, {0, 0, 0}, {0, -0.8, -0.8} },

    { {-0.8, -0.8, -0.8}, {-0.8, -0.8, 0}, {-0.8, 0, 0} },
    { {-0.8, -0.8, -0.8}, {-0.8, 0, 0}, {-0.8, 0, -0.8} },

    { {0, 0, 0}, {0, 0, -0.8}, {-0.8, 0, -0.8} },
    { {0, 0, 0}, {-0.8, 0, -0.8}, {-0.8, 0, 0} },

    { {0, -0.8, -0.8}, {0, -0.8, 0}, {-0.8, -0.8, 0} },
    { {0, -0.8, -0.8}, {-0.8, -0.8, 0}, {-0.8, -0.8, -0.8} },

    { {0, -0.8, 0}, {0, 0, 0}, {-0.8, 0, 0} },
    { {0, -0.8, 0}, {-0.8, 0, 0}, {-0.8, -0.8, 0} },

    { {0, 0, -0.8}, {0, -0.8, -0.8}, {-0.8, -0.8, -0.8} },
    { {0, 0, -0.8}, {-0.8, -0.8, -0.8}, {-0.8, 0, -0.8} }
  };

  matrix viewport = newmat(4, 4);
  identity(&viewport);
  viewport.m[0][3] = WIDTH/2.;
  viewport.m[1][3] = HEIGHT/2.;
  viewport.m[2][3] = 255/2.;
  viewport.m[0][0] = WIDTH/2.;
  viewport.m[1][1] = HEIGHT/2.;
  viewport.m[2][2] = 255/2.;

  matrix projection = newmat(4, 4);
  identity(&projection);
  projection.m[3][2] = -1./-2.;

  float pi180 = 3.14159/180.f;
  float cosz = cosf(15. * pi180);
  float sinz = sinf(15. * pi180);
  float cosy = cosf(5. * pi180);
  float siny = sinf(5. * pi180);

  matrix roty = newmat(3, 3);
  roty.m[0][0] = cosy;
  roty.m[0][1] = 0.;
  roty.m[0][2] = siny;

  roty.m[1][0] = 0.;
  roty.m[1][1] = 1.;
  roty.m[1][2] = 0.;

  roty.m[2][0] = -siny;
  roty.m[2][1] = 0.;
  roty.m[2][2] = cosy;

  matrix rotz = newmat(3, 3);
  rotz.m[0][0] = cosz;
  rotz.m[0][1] = -sinz;
  rotz.m[0][2] = 0.;

  rotz.m[1][0] = sinz;
  rotz.m[1][1] = cosz;
  rotz.m[1][2] = 0.;

  rotz.m[2][0] = 0.;
  rotz.m[2][1] = 0.;
  rotz.m[2][2] = 1.;

  //matrix rot = matmul(rotz, roty);

  for (int i = 0; i < 12; i++) {
    //vec3 screenv1 =
    draw_tri((short)(project(persp(rot(cube_faces[i].v1))).x),
	     (short)(project(persp(rot(cube_faces[i].v1))).y),

	     (short)(project(persp(rot(cube_faces[i].v2))).x),
	     (short)(project(persp(rot(cube_faces[i].v2))).y),

	     (short)(project(persp(rot(cube_faces[i].v3))).x),
	     (short)(project(persp(rot(cube_faces[i].v3))).y),
	     RED);
  }
}

void main() {
  set_sys_clock_khz(150000, true);
  stdio_init_all();

  dbus_rptr = dbus_wptr = dbus_buf;
  dbus_pio = pio0;
  dbus_pio_irq = PIO0_IRQ_0;
  dbus_offset = pio_add_program(dbus_pio, &dbus_program);
  dbus_sm = pio_claim_unused_sm(dbus_pio, true);
  dbus_program_init(dbus_pio, dbus_sm, dbus_offset, D0);
  pio_gpio_init(dbus_pio, CSB);
  pio_gpio_init(dbus_pio, PH2);
  pio_gpio_init(dbus_pio, RWB);
  gpio_set_dir(CSB, GPIO_IN);
  gpio_set_dir(PH2, GPIO_IN);
  gpio_set_dir(RWB, GPIO_IN);
  pio_sm_set_jmp_pin(dbus_pio, dbus_sm, RWB);
  pio_set_irq0_source_enabled(dbus_pio, pis_interrupt0, true);
  irq_set_exclusive_handler(dbus_pio_irq, read_dbus);
  irq_set_enabled(dbus_pio_irq, true);
  pio_sm_set_enabled(dbus_pio, dbus_sm, true);

  init_VGA();
  fill_rect(0, 0, 640, 480, CYAN);
  set_text_size(1);
  set_text_wrap(1);
  set_cursor(0, 0);
  set_text_color(BLACK, CYAN);

  add_repeating_timer_ms(500, toggle_cursor, NULL, &timer);

  //threed_demo();

  while (true) {
    dbus_task();
  }
}

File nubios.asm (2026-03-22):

  .setcpu "65816"
  .include "hardware.inc"
  .include "bios.inc"
  .include "vga.inc"
  .include "cf.inc"
  .include "fat16.inc"

  MHZ_MULT = 4 ; current installed clock speed
  JIF_COUNT = 9999 * MHZ_MULT ; 100hz counter

  .export putchar
  .export putchar_serial
  .export prbyte
  .export getchar
  .export getchar_old_serial
  .export puts
  .export reset
  
  .segment "CODE"
  .include "xmodem.asm"
  .include "prng.asm"
  .include "filesystem.asm"
  .include "math.asm"

  .A8
  .I8

init:
  lda #$40 ; RTI
  ;sta irqvec ; no handlers by default
  sta nmivec ; user can add a jmp or jml to their own
  lda #$4c
  sta irqvec
  lda #<irq_handler
  sta irqvec + 1
  lda #>irq_handler
  sta irqvec + 2

  sta inbuf_read
  sta inbuf_write ; init buffer pointers
  
  lda #$00
  sta ACIA_STAT ;reset
  lda #$1f ;8n1, 19200
  sta ACIA_CTRL
  lda #$0b ; dtrb low rx irq disabled rtsb low no parity normal echo mode
  sta ACIA_CMD

  stz jifs
  stz secs
  stz mins
  stz hrs

  lda #%11000000
  sta VIA1_IER ; enable t1 interrupts
  lda #$43
  sta VIA1_ACR ; t1 continuous pb7 off

  stz VIA1_DDRA ; all inputs
  lda #%00001000
  sta VIA1_PCR ; ca2 handshake output, ca1 negative edge triggered
  lda #$82
  sta VIA1_IER ; enable ca1 interrupts
  
  rts
  
reset:
  clc
  xce
  ACC_16
  lda #$01ff
  tcs
  lda #$0000
  tcd
  ACC_8
  jsr init
  cli
  lda #<JIF_COUNT
  sta VIA1_T1C_L
  lda #>JIF_COUNT
  sta VIA1_T1C_H

  lda #RESET
  sta VGA_DATA
  LD_PTR str_boot
  jsr puts

  ; monitor line fetch
@ready:
  lda #']'
  jsr putchar
  jsr readline
  bcs @ready ; try again on error

  ; now process line
  jsr toupper
  jsr parseline
  bra @ready

parseline:
  txy ; y = line length backup, not including null
  ldx #$00
  lda linebuf, x
  ; xmodem recv command?
  cmp #'X'
  bne @notx
  inx
  lda linebuf, x
  cmp #'R'
  bne @notxr
  inx
  lda linebuf, x
  jsr isdigit
  bcc @default_load
  jsr getaddr
  bra :+
@default_load: ; receive files at user_start if not otherwise specified
  lda #<user_start
  sta workwl
  lda #>user_start
  sta workwh
:
  jmp xmodem_recv
@notxr:
  cmp #'S'
  bne :+
  jmp xmodem_send
:
  dex
  lda linebuf, x
@notx:
  ; other non hex digit = error
  jsr isdigit
  bcs :+
  jmp bad_input
:	
  ; linebuf must contain a hex address, get it
  jsr getaddr
  bcs :+
  jmp bad_input
:	
  inx
  lda linebuf, x
  cmp #':'
  bne :+
  jmp do_poke
:	
  cmp #'G'
  bne :+
  jmp do_run
:	
  cmp #'.'
  bne @skiprange
  ; TODO refactor this into another getaddr call
  ; get second addr, max of 1 page for now
  inx
  lda linebuf, x
  pha
  inx
  lda linebuf, x
  sta workb
  pla
  jsr asc2byte
  sta workw2h
  inx
  lda linebuf, x
  jsr isdigit
  bcs @shortskip2
  ; short zero page addr
  dex
  lda workw2h
  sta workw2l
  stz workw2h
  bra @skips2
@shortskip2:
  pha
  inx
  lda linebuf, x
  sta workb
  pla
  jsr asc2byte
  sta workw2l
@skips2:
  sec
  lda workw2l
  sbc workwl
  tax
  inx ; make the range inclusive
  bra @skipr2
@skiprange:
  ldx #$01
@skipr2:
  jsr peek
@quit:
  rts

bad_input:
  LD_PTR str_err_bad_input
  jsr puts
  rts

peek: ; addr in workw, count in x
  ; todo: should be able to use 16 bit range easily
  lda workwh
  xba
  lda workwl
  jsr prword
  lda #':'
  jsr putchar
  ldy #24
@loop:
  lda #' '
  jsr putchar
  lda (workw)
  jsr prbyte
  inc workw
  dey
  bne :+
  CRLF
  .repeat 5
  lda #' '
  jsr putchar
  .endrep
  ldy #24
:	
  dex
  bne @loop
  CRLF
  rts

do_poke: ; starts with x pointing at the :
  inx
  lda linebuf, x
  cmp #' '
  bne @skip1
  inx
  lda linebuf, x
@skip1:
  jsr isdigit
  bcs :+
  jmp bad_input
:	
  xba
  inx
  lda linebuf, x
  jsr isdigit
  bcs :+
  jmp bad_input
:	
  sta workb
  xba
  jsr asc2byte
  sta (workw)
  inx
  lda linebuf, x
  cmp #' '
  bne @end
  inc workw
  inx
  lda linebuf, x
  bra @skip1
@end:
  rts

do_run:
  ldx #$00
  jsr (workw, x)
  sep #$30
  rts

  ;---------------------------------------
  ;  Line buffer manipulation procedures
  ;---------------------------------------

readline: ; return line length in x, carry set on error
  ldx #$00
@loop:
  jsr getchar
  bcc @loop
  cmp #CR
  bne @skip ; regular character, add to buffer
  cpx #$00 ; return pressed on empty buffer, ignore
  beq @loop
  stz linebuf, x ; null terminate and finish
  CRLF
  clc
  rts
@skip:
  cmp #BS
  bne :++
  cpx #0
  beq :+ ; don't backspace if there's nothing to delete
  dex ; delete character from buffer and display
  lda #BACKSPACE
  sta VGA_DATA
:	
  bra @loop
:
  cmp #$1f
  bcc @loop
  cmp #$7f
  bcs @loop ; ignore unprintable characters
  sta linebuf, x
  jsr putchar ; echo typed char
  inx
  beq @line_ovf
  bra @loop
@line_ovf:
  LD_PTR str_err_line_ovf
  jsr puts
  sec
  rts

toupper: ; converts linebuf to uppercase, ignoring non letters
  phx
  ldx #$00
@loop:
  lda linebuf, x
  beq @quit
  cmp #'A'
  bcc @skip2 ; a < A
  cmp #'z' + 1
  bcs @skip2 ; a > z
  cmp #'a'
  bcs @skip1 ; a >= a
  cmp #'Z' + 1
  bcc @skip1 ; a <= Z
  bra @skip2 ; a is not letter
@skip1: ; A <= a <= Z or a <= a <= z
  cmp #'a'
  bcc @quit ; already uppercase
  sec
  sbc #$20
  sta linebuf, x
@skip2:
  inx
  bra @loop
@quit:
  plx
  rts

getaddr: ; get 2 or 4 digit addr from linebuf[x] and put it in workw
  ; carry set = ok, carry clear = err
  xba ; first digit should already be in a
  inx ; parseline will only allow a digit through so no need to check
  lda linebuf, x
  sta workb
  xba
  jsr isdigit
  bcc @err ; bad char in 2nd digit
  jsr asc2byte
  sta workwh
  inx
  lda linebuf, x
  jsr isdigit
  bcs @shortskip
  ; short zero page addr
  dex
  lda workwh
  sta workwl
  lda #$00
  sta workwh
  bra @skip3
@shortskip:
  xba
  inx
  lda linebuf, x
  jsr isdigit
  bcc @err ; only 3 digits typed
  sta workb
  xba
  jsr isdigit
  bcc @err ; bad char in the middle
  jsr asc2byte
  sta workwl
@skip3:
  sec
  rts
@err:
  clc
  rts

  ;---------------------------------------
  ;  Text manipulation/Output procedures
  ;---------------------------------------

putchar_serial:
  xba
  lda ACIA_STAT
  and #$10 ; thank you rockwell for making parts that actually work
  beq putchar_serial
  xba
  sta ACIA_DATA
  rts

putchar: ; TODO maybe make it a macro since it's just 1 instruction
  sta VGA_DATA
  rts

puts: ; address in workw, zero terminated
  lda (workw)
  beq @quit ; zero terminator
  jsr putchar
  inc workwl
  bne @skip
  inc workwh
@skip:
  bra puts
@quit:
  rts

puts_len: ; address in workw, length in x
  stx workb
  ldy #$00
@loop:
  cpy workb
  beq @quit
  lda (workw), y
  jsr putchar
  iny
  bra @loop
@quit:
  rts

asc2nyb: ; ascii in a, returned nibble is least significant part of a
  sec
  sbc #$30 ; '0' ascii
  cmp #CR
  bcc @skip
  sbc #$07 ; difference between ascii '9' and 'A'
@skip:
  and #$0f
  rts

asc2byte: ; first nyb in a, second in workb, returned in a
  jsr asc2nyb
  asl
  asl
  asl
  asl
  xba
  lda workb
  jsr asc2nyb
  sta workb
  xba
  ora workb
  rts
  
prword:
  xba
  jsr prbyte
  xba
  jsr prbyte
  rts
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

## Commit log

2024-10-05 Add control flow instructions and debug info
2024-10-15 Rename some files for clarity
    [mmap-8k-rom.cfg]
2024-10-22 wozmon and basic attempts
    [8k-w-mon.cfg, tbtest.cfg]
2024-10-26 Fix V flag bug in ADC
2024-11-01 Continue implementing and testing IL prototype
2024-11-01 Fix errors in debug printing, SBC, and RTI
2024-11-08 Port monitor to UART I/O and add improvements
2024-11-09 Simple memory map for RAM based programs
    [user-ram.cfg]
2025-01-10 Switch to accelerated texture rendering, fix some warns
2025-02-28 Adjust for 65816, fix xmodem receive
    [816-8k-rom.cfg]
2025-04-19 New ld config for larger ROM
    [816-v2.cfg]
2025-09-08 Separate out xmodem from bios code, switch to buffered IRQ based input (doesn't work great and might revert)
    [nubios.asm]
2025-09-08 Clean out old/unused files
    [816-8k-rom.cfg, 8k-w-mon.cfg, mmap-8k-rom.cfg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]
2025-09-08 Upload current Kicad files
    [816-v2.kicad_pcb, 816-v2.kicad_sch, io.kicad_sch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]
2025-09-09 Add photo of current proto board layout
    Upper left is a PCB for the power and reset circuitry that I designed in order to practice KiCad
2025-12-18 Add pico 2 vga code and updated mandelbrot demo
2026-01-04 Switch to VGA+PS/2 for I/O, add Xmodem send command
2026-01-09 Minor fixes/edits to bios
    [nubios.asm]
2026-01-20 Switch to 16-color VGA + small cleanups
2026-01-20 Update KiCad files to get ready for PCB design
    [816-v2.kicad_pcb, 816-v2.kicad_sch, io.kicad_sch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]
2026-01-31 CPLD files for new board
2026-01-31 Update KiCad files
    [816-v2.kicad_pcb, 816-v2.kicad_sch, io.kicad_sch]
2026-02-12 Update KiCad files new pcb revision, hopefully working
    [816-v2.kicad_pcb, 816-v2.kicad_sch, io.kicad_sch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]
2026-02-12 Update ATF1504 logic to reflect new schematics
2026-02-15 Rename pico files
2026-03-01 Update CF code for on-bus PCB version
2026-03-02 Update KiCad files to reflect ROM WE bodge
    [816-v2.kicad_pcb, io.kicad_sch, power-reset.kicad_sch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]
2026-03-03 Add PRNG, clean up and rearrange zeropage
    [user-ram.cfg]
2026-03-22 Boost UART speed to 19200 + rom padding change
    [816-v2.cfg]
